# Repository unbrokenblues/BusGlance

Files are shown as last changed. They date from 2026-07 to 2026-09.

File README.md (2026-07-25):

# BusGlance

A tiny ESP32 + 4.2" e-paper display that shows live Singapore bus arrival
times (from LTA DataMall) for two stops, plus a daily uplifting quote.
Battery-powered, sleeps overnight, and pings your phone when the battery is low.



## Features

- **Live bus times** for a home stop and the opposite stop, refreshed every 60s.
- **Fast black & white e-paper** (~1.2s refresh) with a Bauhaus-minimalist layout.
- **"Arriving soon" tag** — buses <= 3 min show white-on-black.
- **365 built-in quotes** (scripture, motivation, manifesting), one per day.
- **Battery smart:** sleeps 00:00-05:00 with WiFi off; on-screen low-battery
  icon plus a phone push via [ntfy.sh](https://ntfy.sh).
- Runs ~10 days on a 2000 mAh LiPo.

## Hardware

- ESP32 dev board (classic ESP32)
- WeAct 4.2" e-paper, 400x300 (driven in black & white)
- LiPo battery (2000 mAh)

Wiring and full build notes are in [PROGRESS.md](PROGRESS.md).

## Setup

1. Install [arduino-cli](https://arduino.github.io/arduino-cli/) and the ESP32 core:
   ```bash
   arduino-cli core install esp32:esp32
   arduino-cli lib install GxEPD2 ArduinoJson
   ```
2. Copy the secrets template and fill in your own values:
   ```bash
   cp bus_display/secrets.h.example bus_display/secrets.h
   ```
   Set your WiFi, your [LTA DataMall](https://datamall.lta.gov.sg/) API key,
   and a private ntfy topic.
3. Adjust the stops, bus numbers, and options at the top of
   `bus_display/bus_display.ino`.
4. Build and upload:
   ```bash
   cd bus_display
   arduino-cli compile --fqbn esp32:esp32:esp32 .
   arduino-cli upload -p YOUR_PORT --fqbn esp32:esp32:esp32 .
   ```

## Note

`secrets.h` is git-ignored so your WiFi password and API key never get
committed. Never commit real credentials.

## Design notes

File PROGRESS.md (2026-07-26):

# BusGlance — Progress Notes

_Last updated: 2026-07-27_

## Update 2026-07-27 — live on hardware

- **Flashing DONE.** Firmware runs on the real board: WiFi + LTA + weather all
  live, crisp black-on-white, overnight sleep re-enabled (`DEBUG_NO_NIGHT_SLEEP
  = false`).
- **Partial refresh does NOT work on this panel.** Tested on hardware: partial
  updates render as grey, ghosted mush (this is a 3-color GDEY042Z98 panel
  driven as B/W). Kept the light-sleep + partial-refresh plumbing but set
  `FULL_REFRESH_EVERY = 1` (full refresh every cycle = crisp, with the black
  flash). The flash takes ~10-14s to settle — unavoidable on this panel.
- **Fix = swap to a TRUE B/W panel: `GDEY042T81`** (WeAct 4.2" Black-White,
  SSD1683, ~$19.46, WeAct Studio Official Store on AliExpress). Confirmed by a
  buyer review running it with partial refresh. Drop-in: same wiring, same case,
  same driver — just set `FULL_REFRESH_EVERY = 15` for smooth flash-free ~0.4s
  partial refresh. NOT yet ordered.
- **Font/icon polish:** minutes auto-shrink so 3-digit bus numbers never overlap
  the "N min"; weather icons redrawn as uniform 2px outlines.
- **Battery:** LiPo confirmed safe (board `+` = red wire). Charge via USB-C
  (board charges while running). Battery low-warning (on-screen + ntfy push to
  topic `busglance-dicky`) is a no-op on this board — pin 35 can't read VBAT, so
  it fail-safes silent. Decision: just **charge weekly** (~7-10 day runtime).

An ESP32 + 4.2" e-paper display that shows live Singapore bus arrival times
(LTA DataMall) for two stops, plus a daily uplifting quote. Battery-powered,
sleeps overnight.

---

## Status at a glance

- **Software: DONE.** The sketch compiles cleanly (arduino-cli, ESP32 core).
- **Blocked on ONE hardware step:** the ESP32's header pins need to be
  **soldered on** before anything can connect. A soldering iron kit (KIPRUN,
  ~$13) was ordered. Everything else is solderless.
- **Not yet uploaded** to the board (waiting on the soldering).

**When you come back:** get the pins soldered → wire the display (map below)
→ plug in USB-C → upload → verify. Roughly 15 minutes once the iron is here.

---

## Hardware inventory

| Item | What it is | Notes |
|---|---|---|
| ESP32 "Lite" (USB-C) | The brain. Confirmed **classic ESP32** (so GPIO 23/18 = SPI). | Came with **loose header pins** — must be soldered on. |
| WeAct 4.2" e-paper, 400x300 | The screen. Physically a **3-color (b/w/red)** panel (GDEY042Z98). | Driven in **black & white** on purpose (see decisions). Factory demo showed red = confirmed 3-color. |
| Rainbow JST cable | 8-wire cable, JST plug → 8 female DuPont ends. | Plugs into the display's white socket (no solder). Other end pushes onto ESP32 pins. |
| 2x4 pin block (spare) | Alt connector for the display. | **Not used** — we use the JST cable. |
| 2 long pin strips | Male headers for the ESP32 edges. | These get soldered onto the ESP32. |

---

## Wiring map (display label → ESP32 pin)

Plug the JST cable into the display's white socket, then push each wire onto
the matching ESP32 pin. **Power is 3.3V — never 5V.**

| Display pin | ESP32 pin | Purpose |
|---|---|---|
| VCC | **3V3** | power (3.3V only) |
| GND | **GND** | ground |
| SDA | **GPIO23** | data (labeled SDA but it's SPI MOSI) |
| SCL | **GPIO18** | clock (labeled SCL but it's SPI SCK) |
| CS  | **GPIO5**  | chip select |
| D/C | **GPIO17** | data/command |
| RES | **GPIO16** | reset |
| BUSY| **GPIO4**  | busy |

Leave the display's "3-Lines / 4-Lines SPI" jumper at its factory setting.

**You do NOT need to solder all the ESP32 pins.** Only these matter:
`3V3, GND, 23, 18, 5, 17, 16, 4` (+ `35` if using the battery monitor).
On this board, the left edge (USB-C at top) conveniently has 3V3 + all six
display signals (23,18,5,17,16,4) — solder that whole strip. GND and 35 are on
the other edge — solder at least GND (and 35), plus a support pin so the strip
isn't wobbly. Skip the rest. Battery: 2000 mAh LiPo (~10 days/charge).

---

## Key settings (top of `bus_display/bus_display.ino`)

- **WiFi + LTA API key:** set in `bus_display/secrets.h` (git-ignored). Copy
  `secrets.h.example` to `secrets.h` and fill in your values.
- **Stops:** Home = `59399` (buses 807, 860, 806, 663) · Opposite = `59391` (buses 804, 807).
- **Refresh:** every `REFRESH_SECONDS = 60`.
- **Active hours:** 05:00–24:00. Sleeps 00:00–05:00 with WiFi off.
- **Battery monitor:** on-screen low-batt icon + phone push (ntfy.sh). Reads
  `BATTERY_ADC_PIN = 35` (÷2 divider), warns below `LOW_BATT_VOLTS = 3.45`.
  Set `NTFY_TOPIC` to something private; fail-safe if the pin isn't wired.
- **Charge frequency:** ~once a week on a 1500–2000 mAh LiPo (draw ~200 mAh/day,
  dominated by the 60s WiFi wakes). Cheap-board idle draw is the wild card.

---

## Design decisions (why things are the way they are)

1. **Black & white, not red.** The panel is physically 3-color, but 3-color
   mode is stuck at ~15s refresh + a 3-minute minimum interval. Driving it in
   B/W (the `GDEY042T81` driver) unlocks a **~1.2s fast refresh with no
   minimum**, so we can update every 60s. Verified against the datasheet and
   the installed library. Red was the *only* thing forcing slow updates.
2. **"Arriving soon" cue = black tag.** A bus <= 3 min away (or NOW) shows its
   minutes as **white text on a filled black box** (replaces the red idea,
   works in B/W, and is more Bauhaus anyway).
3. **Layout = Bauhaus minimalist.** Centered uppercase HOME / OPPOSITE on solid
   black bars; Home in a 2x2 grid; Opposite side-by-side; numbers hard-left,
   minutes hard-right on a clean grid.
4. **Overnight sleep saves battery.** Old code hit WiFi every wake all night.
   Now it reads the clock from the ESP32's RTC (kept alive through deep sleep)
   and, if it's 00:00–05:00, sleeps straight to 5am **without powering WiFi**.
5. **Quotes are built-in, not an API.** Researched quote APIs live: Quotable is
   dead, DummyJSON has mangled capitalization, FavQs can be dark, Bible verses
   are mostly too long. Most stable = a **built-in curated list**. Now **365
   quotes** (scripture + affirmations + proverbs + classic motivation), one per
   day by date, all validated ASCII + short. Zero network, nothing to maintain.

---

## VERIFY ON FIRST BOOT (the 3 things we couldn't test without hardware)

1. **Display driver line.** We drive a 3-color panel in B/W mode. Very likely
   fine (same SSD1683 controller), but if the screen is **blank, faint, or
   ghosted**, that's the switch to flip. Search `DISPLAY DRIVER` in the sketch.
2. **HTTPS / TLS.** Both the bus fetch and (previously) quotes use HTTPS. If
   fetches fail on the real board, the fix is a `WiFiClientSecure` +
   `client.setInsecure()` before `http.begin(...)`. Quick change.
3. **RTC time across deep sleep.** The overnight-sleep logic assumes the clock
   survives deep sleep (standard ESP32 behavior). Confirm it wakes correctly
   at ~5am and doesn't sit online all night.
4. **Battery-voltage pin.** The Serial log prints `Battery volts:` each cycle.
   Confirm it reads realistically (~3.7–4.2V on a charged LiPo). If it prints
   -1 or nonsense, the board doesn't expose battery voltage on pin 35 — either
   fix `BATTERY_ADC_PIN`/`BATTERY_DIVIDER`, add a 2-resistor divider, or set
   `BATTERY_MONITOR = false`. Also set up ntfy (below) for the phone push.

---

## Exact next steps

1. **Solder the two header strips onto the ESP32** (pins pointing down, USB-C
   side up). Or have a makerspace/shop do it.
2. **Wire the display** using the map above (all unplugged from USB).
3. **Plug in USB-C.** Find the serial port:
   ```bash
   arduino-cli board list
   ```
4. **Upload** (replace PORT with what step 3 shows, e.g. /dev/cu.usbserial-XXXX):
   ```bash
   cd "/Users/dickyagustiady/Projects/BusSchedule/bus_display"
   arduino-cli upload -p PORT --fqbn esp32:esp32:esp32 .
   ```
   (If upload fails to start, hold the BOOT button on the ESP32 while it connects.)
5. **Watch the serial log** to confirm WiFi + fetch:
   ```bash
   arduino-cli monitor -p PORT -c baudrate=115200
   ```

To recompile after any edit:
```bash
cd "/Users/dickyagustiady/Projects/BusSchedule/bus_display"
arduino-cli compile --fqbn esp32:esp32:esp32 .
```

---

## First-time soldering cheat sheet (for the header pins)

The easiest kind of soldering — big holes, forgiving. Steps:

1. Let the iron reach ~350C (the kit's digital display shows temp).
2. Sit the pin strip in the ESP32's holes, **plastic spacer flush**, USB side up.
3. **Solder ONE end pin first**, then check the strip sits straight/flush. If
   it tilted, re-melt that joint and nudge it square. *Then* do the rest.
4. Per joint: touch the iron to the pin **and** the gold ring for ~1 second,
   feed a little solder into the joint (not onto the tip), remove solder, then
   remove iron. You want a small shiny cone, not a blob.
5. GND pins take a touch longer to heat (they sink heat) — be patient.
6. Do all pins on both strips so the header is mechanically solid.
7. Rest the hot iron in its stand; wet the sponge to wipe the tip.

Then the display side is 100% solderless — the JST cable just clicks in.

---

## Environment (already set up on this Mac)

- `arduino-cli` v1.5.1 (via Homebrew)
- ESP32 core `esp32:esp32` v3.3.11
- Libraries: GxEPD2, ArduinoJson (+ Adafruit GFX/BusIO)
- Board FQBN: `esp32:esp32:esp32`
- Sketch: `BusSchedule/bus_display/bus_display.ino` (compiles at ~86% flash)

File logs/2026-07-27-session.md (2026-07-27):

# BusGlance / Waktu Session Log — 2026-07-27

Long session. Took BusGlance from a jumper-wire prototype to a trustworthy,
cordless device, rebuilt the case off the real board model, and made key
product decisions for Waktu.

## Display / firmware (bus_display.ino)
- **3 bus timings per service** (NextBus/2/3): big next + two small raised numbers.
- **Dropped "min"** from the numbers; added a tiny **"MIN" legend** on the right of
  each bar.
- **"NOW" → "0"** (arriving = 0 min) — compact, no overlap.
- **Sticky weather**: keep last-good reading on a failed fetch instead of blanking.
- **Weather icon raised + rain drops shortened** so they clear the temp text.
- **Fail-loud failsafe** (the big safety win):
  - Retry NTP **every cycle** (was one-shot at boot) → clock self-heals.
  - Guard `minutesUntilArrival`: no valid clock → return -1 (kills the ~29M
    garbage minutes) + drop absurd (>240min) values.
  - **OFFLINE staleness banner**: if the LTA API isn't reached (or clock invalid)
    for >5 min, a black `! OFFLINE - times as of HH:MM` bar covers the top so
    stale times can never be mistaken for live.

## Case — rebuilt in CadQuery off the REAL board model
- Installed **CadQuery** (system python3 `/usr/bin/python3`, v2.5.2).
- Downloaded WeAct's **`WeAct-EpaperModule-4.2 Board 3D.step`** from
  github.com/WeActStudio/WeActStudio.EpaperModule → `case/models/weact_42.step`.
- Extracted EXACT geometry: board **91.8 × 89.8 mm**, holes **3.2mm dia, 2.8mm
  inset** (86.2 × 84.2 hole-to-hole). Confirmed my measured 91×89 was ~right (not
  swapped). Applied exact values to both the trimesh case (`busglance_case.py`)
  and the new CadQuery build (`busglance_case_cq.py`).
- CadQuery case: flat front/back + filleted vertical edges, rounded window
  (shifted so the bottom PCB strip is hidden), display screwed to the front,
  ESP32 **screwed to the back** via its 2 measured M2 holes on a raised-floor
  cradle, USB-C slot moved to the correct back-of-case depth, snap-fit back.
- Fit check: overlaid the real board's holes vs the case pilots → **0.00mm**
  misalignment.
- The messy trimesh `rbox` pillow shape was replaced with real fillets.

## Hardware saga (all resolved)
- **Bent the ESP32 header pins flat** to slim the wire stack (two-pliers method).
- After rewiring, display froze / showed garbage → chased it down: NOT wiring or
  WiFi. Root cause = **NTP timeout on a cold boot** → no clock → 29M garbage
  minutes. Fixed by the failsafe above. (Also learned: `arduino-cli monitor`
  can't read serial through this CH340 dongle — the display is the ground truth,
  not the serial log.)
- **Battery: RESOLVED — it works.** It was just never fully charged. The board
  DOES auto-charge over USB-C; charge LED on = charging, off = full. Runs
  cordless ~7-10 days. Charge weekly.
- **Battery monitor: conclusively impossible on this board.** Ran an ADC scan
  (results shown on e-paper, since serial is dead) across GPIO 32/33/34/35/36/39
  — NO pin carries the battery voltage (all ~142mV floor; none near ~2000mV, none
  shift with USB). So the low-batt icon + ntfy push can't work without adding a
  2-resistor divider to GPIO 34. Decision: charge weekly, skip the monitor.
  Scanner kept at `adc_scan/adc_scan.ino`.

## Product / process decisions
- **Wall mount:** the printed keyholes were non-functional (no head clearance in
  a thin, packed case). Real answer for a light case = **velcro / Command
  strips** (removable, no wall damage). A slide-on bracket is the "proper" option
  if wanted later.
- **Closure:** no super glue (it's permanent AND cyanoacrylate fogs e-paper).
  Use screws / magnets / hot glue / tape.
- **"How do real products look clean inside?"** — custom PCB (bare ESP32 + RTC +
  FPC display connector, no dev board / jumper wires) + injection-molded case.
  The prototype's mess doesn't carry over; its job is to prove firmware + demand.
- **Red on e-paper:** would make refresh ~2× slower (~20s) AND force a ~3-min
  minimum interval → bad for a 60s bus display. Skip red; go true B/W for speed.

## Waktu (PRD updated — Drive-synced, not git)
- **Dropped ALL physical input** — no button, no touch, no rotary dial.
- **Setup via phone WiFi captive portal** (no app; fallback 192.168.4.1);
  **re-entry via power-cycle** ("the plug is the button"). Bluetooth rejected
  (needs an app). Cleaner case (no holes), cheaper BOM.
- RTC locked as **DS3231 (TCXO)** — DS1302/DS1307 drift ~1-2 min/month,
  unacceptable for prayer times; DS3231 ~±1 min/year.
- Prototype BOM ~$28-30; volume ~Rp200-290k vs Rp399-599k retail.

## Current state
- BusGlance: working, cordless, fail-loud. Firmware + CadQuery case committed.
- Still to order: true B/W **GDEY042T81** panel (drop-in, fast refresh; buy 2 —
  one for BusGlance upgrade, one for Waktu). Print the CadQuery case.
- Case depth is 28mm for the (now-slimmer) wire stack — could drop to ~12mm if
  wires are soldered direct / pins trimmed; re-measure the flat stack when ready.

## Pick up next
1. Order 2× GDEY042T81 B/W panels.
2. Print the CadQuery front + back; verify fit with the real board dims.
3. (Optional) slim wiring → shallow case; (optional) GPIO34 divider for batt push.
4. Waktu: start firmware (offline prayer-time calc is the real new work).

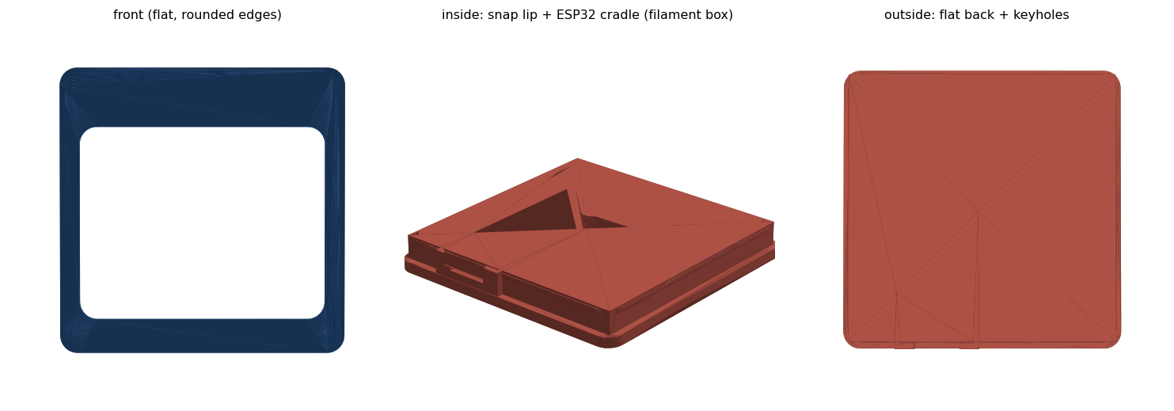
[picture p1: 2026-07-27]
case/preview.png

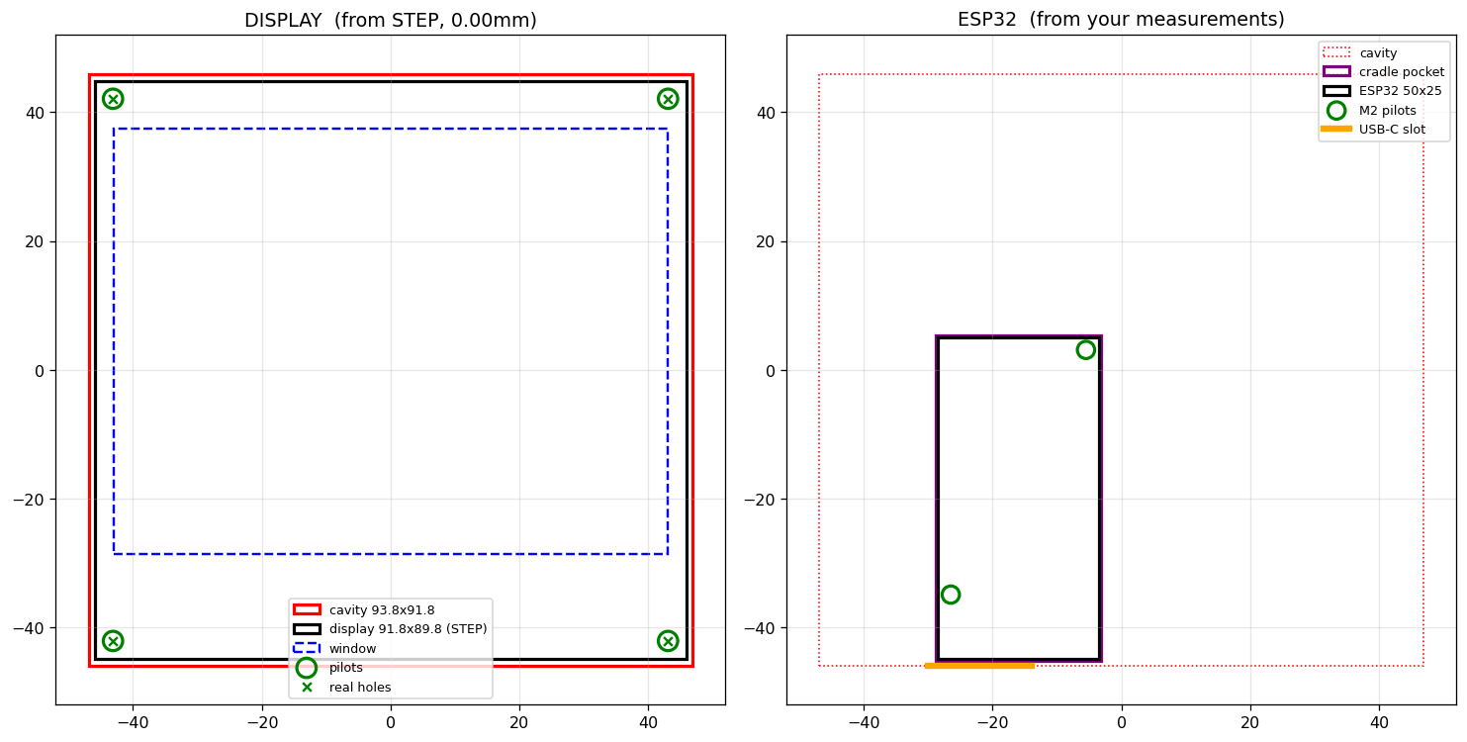
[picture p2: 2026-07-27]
case/fit_check.png

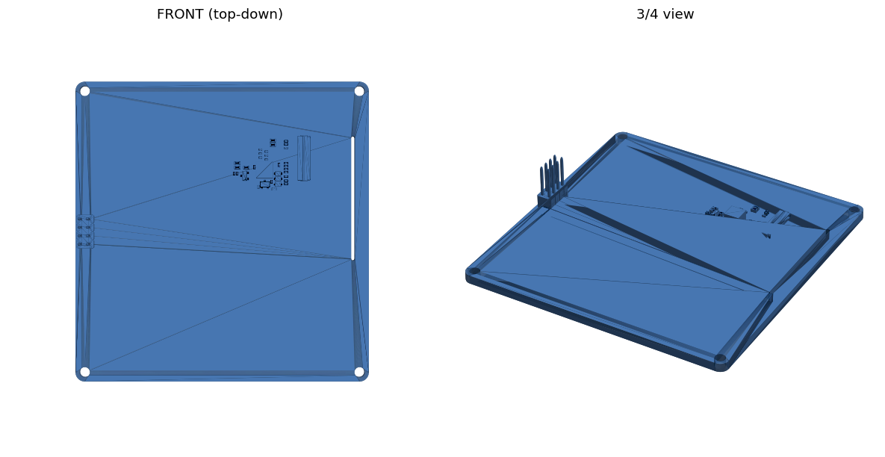
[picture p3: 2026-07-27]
case/models/weact_render.png

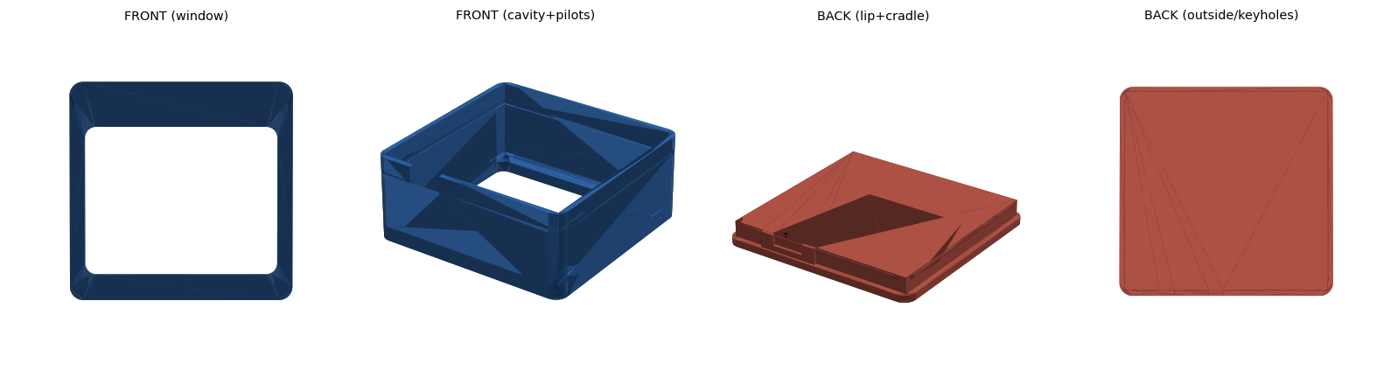
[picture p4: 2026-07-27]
case/preview_cq.png

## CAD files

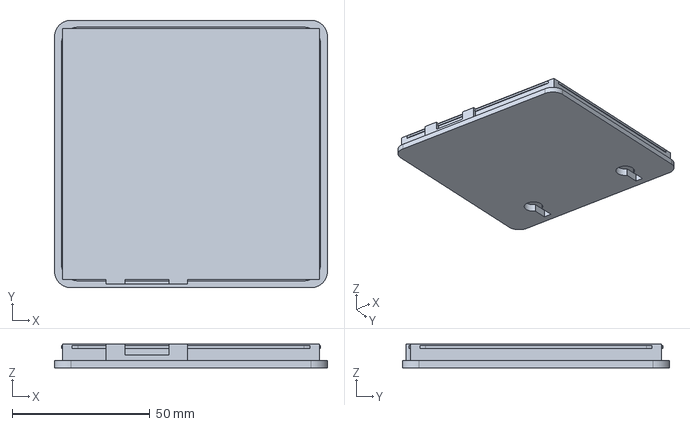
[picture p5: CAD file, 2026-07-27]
case/back_cover.step
99.0 x 97.0 x 8.60 mm

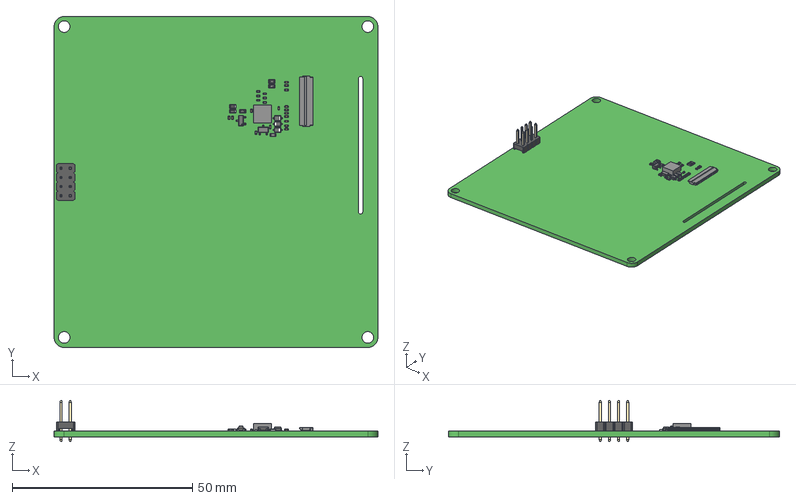
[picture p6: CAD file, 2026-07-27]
case/models/weact_42.step
89.8 x 91.8 x 11.5 mm
R0603 x 5
Extruded x 6
pin_header_awl254-dg-g08d
User Library-SOT23-3
Mid_Body x 9
Mark x 9
Leader x 3
FH34SRJ-24S-0.5SH_RGB4408131
SOD323 x 3

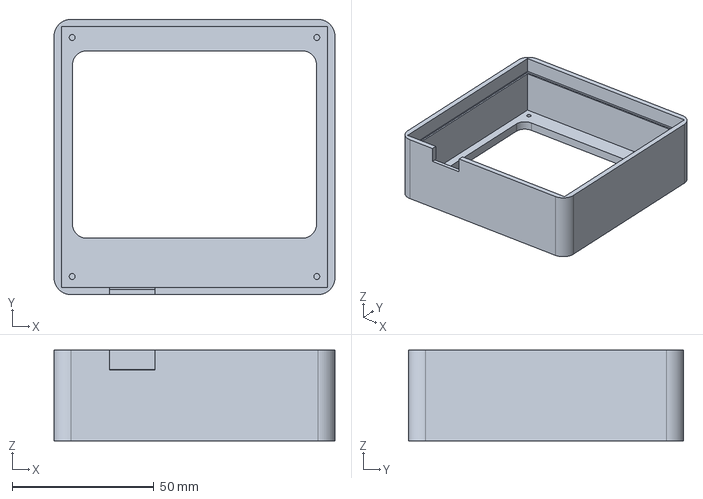
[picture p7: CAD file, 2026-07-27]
case/front_shell.step
99.0 x 97.0 x 32.0 mm

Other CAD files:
case/back_cover.stl
case/front_shell.stl

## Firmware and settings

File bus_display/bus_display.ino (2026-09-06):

/*
  BusGlance - Home Bus Arrival Display
  ESP32 Lite V1.0.0 + WeAct 4.2" E-Paper (400x300)

  WHAT THIS DOES:
  - Connects to WiFi
  - Every 60 seconds (5am - midnight only), fetches live bus arrival
    times from LTA DataMall for two bus stops
  - Draws them on the e-paper screen in black & white, using the panel's
    fast ~1.2s refresh (your stop on top, opposite stop below)
  - Outside 5am-midnight, it sleeps with WiFi off to save battery

  ============ BEFORE YOU UPLOAD ============
  1. Fill in your WiFi name/password below
  2. Your LTA API key is already filled in
  3. Fill in which bus SERVICE NUMBERS you actually want shown
     (e.g. "13", "52", "88") - up to 3 per stop
  4. Check the display driver line (search "DISPLAY DRIVER" below) -
     if the screen shows garbage/nothing, this is the first thing to
     change - tell me and I'll give you the right line.
  ============================================
*/

#include <WiFi.h>
#include <HTTPClient.h>
#include <ArduinoJson.h>
#include <time.h>
#include <esp_sntp.h>
#include <esp_system.h>

#include <GxEPD2_BW.h>
#include <Fonts/FreeSansBold18pt7b.h>
#include <Fonts/FreeSansBold24pt7b.h>
#include <Fonts/FreeSansBold12pt7b.h>
#include <Fonts/FreeSansBold9pt7b.h>
#include <Fonts/FreeSans18pt7b.h>
#include <Fonts/FreeSans9pt7b.h>

// Private credentials live in secrets.h (git-ignored). Copy
// secrets.h.example to secrets.h and fill in your own values.
#include "secrets.h"

// ---------------- USER SETTINGS ----------------

const char* WIFI_SSID     = SECRET_WIFI_SSID;
const char* WIFI_PASSWORD = SECRET_WIFI_PASSWORD;

const char* LTA_API_KEY = SECRET_LTA_API_KEY;

// Your two bus stops
const char* STOP_CODE_HOME     = "59399"; // your stop
const char* STOP_CODE_OPPOSITE = "59391"; // opposite stop

const char* STOP_LABEL_HOME     = "Home";
const char* STOP_LABEL_OPPOSITE = "Opposite";

// Which bus services to show, and in what order.
const char* SERVICES_HOME[4]     = {"807", "860", "806", "663"};
const int   NUM_SERVICES_HOME    = 4;

const char* SERVICES_OPPOSITE[2] = {"804", "807"};
const int   NUM_SERVICES_OPPOSITE = 2;

// Weather (Open-Meteo, free, no API key). Set to your area's coordinates.
const float LATITUDE  = 1.4299;    // your area (northern Singapore)
const float LONGITUDE = 103.8463;
const int   FORECAST_AHEAD_HOURS = 3;  // the "later" slot = now + this many hours

// Refresh interval while awake (seconds). Black & white fast refresh is
// ~1.2s with no 3-minute limit, so we can update often. 60s is a good
// balance of freshness vs battery (30s = fresher but ~half the runtime).
const int REFRESH_SECONDS = 60;

// How often to do a clean FULL (flashing) refresh vs a quiet PARTIAL one.
//   1  => full refresh EVERY cycle: crisp image, but a black flash each time.
//   15 => partial most cycles (no flash) + a full flash ~every 15 min.
// This 3-color panel driven as B/W renders partial refreshes as grey, ghosted
// mush, so we keep it at 1 (full every time). A TRUE B/W GDEY042T81 panel does
// partial cleanly + fast (~0.4s) - swap the panel, then set this to 15.
const int FULL_REFRESH_EVERY = 1;

// A bus this many minutes away (or less) gets the "arriving soon" black tag.
const int SOON_MINUTES = 4;

// DEBUG: while true, the board NEVER sleeps overnight - it keeps refreshing
// 24/7 so we can test past midnight. Set back to false before real use so it
// saves battery by sleeping 00:00-05:00.
const bool DEBUG_NO_NIGHT_SLEEP = false;

// Active hours (24h format) - outside this window the whole board sleeps.
// SG buses run ~5am to midnight, so we sleep 00:00-05:00 to save battery.
const int ACTIVE_START_HOUR = 5;
const int ACTIVE_START_MIN  = 0;
const int ACTIVE_END_HOUR   = 23;
const int ACTIVE_END_MIN    = 59;

// ---- Battery monitor ----
// Only works if your board wires the LiPo to an analog pin (many cheap boards
// do NOT). It's fail-safe: if the reading looks implausible, it stays silent
// instead of false-alarming. On first boot, check the Serial log to confirm
// the voltage is realistic. If your board can't sense it, set this to false.
const bool  BATTERY_MONITOR = true;
const int   BATTERY_ADC_PIN = 34;     // free pin (confirmed via ADC scan) + external 2x100k divider
const float BATTERY_DIVIDER = 2.0;    // external 2x100k divider halves VBAT, so x2 to undo
// Warn below this % (via batteryPercent()'s LiPo curve) - the SAME curve that
// drives the on-screen gauge, so the two can never silently contradict each
// other again. (The old fixed 3.45V threshold actually mapped to ~3% on this
// curve, not the intended ~15-20% - the alert would have fired right before
// shutdown instead of with a useful warning buffer.)
const int LOW_BATT_PERCENT = 15;
const int LOW_BATT_REARM_PERCENT = LOW_BATT_PERCENT + 5;   // re-arm once recovered above this

// Critically low: skip WiFi/HTTPS entirely and just rest. A tired cell can
// brown out mid-WiFi-burst -> reset -> straight back into WiFi -> brownout
// again - a loop with ZERO sleep in between that can drive the LiPo into
// over-discharge. This is the emergency stop for that; no on-screen "charge
// me" UX yet (deliberately deferred), just silently rest and try again later.
const float CRITICAL_BATT_VOLTS = 3.30;
const long  CRITICAL_BATT_SLEEP_SEC = 30L * 60;   // 30 min

// Phone push for low battery via ntfy.sh (free, no account). Install the ntfy
// app, subscribe to YOUR topic below, and alerts arrive on your phone. Change
// this to something private and hard to guess.
const char* NTFY_TOPIC = SECRET_NTFY_TOPIC;

// 365 uplifting quotes - one for each day of the year, picked by date.
// A mix of scripture (public-domain KJV phrasing), affirmations,
// proverbs, and classic motivation. All short + ASCII so they fit.
// Add or edit freely; NUM_QUOTES updates itself.
const char* QUOTES[] = {
  "The Lord is my shepherd; I shall not want. - Psalm 23:1",
  "I can do all things through Christ who strengthens me. - Philippians 4:13",
  "Trust in the Lord with all your heart. - Proverbs 3:5",
  "The Lord is my light and my salvation; whom shall I fear? - Psalm 27:1",
  "Be strong and of a good courage. - Joshua 1:9",
  "Weeping may endure for a night, but joy cometh in the morning. - Psalm 30:5",
  "This is the day which the Lord hath made. - Psalm 118:24",
  "The Lord bless thee, and keep thee. - Numbers 6:24",
  "Let not your heart be troubled. - John 14:1",
  "Cast all your anxiety on him, for he cares for you. - 1 Peter 5:7",
  "Rejoice in the Lord always. - Philippians 4:4",
  "God is our refuge and strength. - Psalm 46:1",
  "Be still, and know that I am God. - Psalm 46:10",
  "Delight thyself also in the Lord. - Psalm 37:4",
  "Commit thy way unto the Lord. - Psalm 37:5",
  "The joy of the Lord is your strength. - Nehemiah 8:10",
  "Let all that you do be done in love. - 1 Corinthians 16:14",
  "Faith is the substance of things hoped for. - Hebrews 11:1",
  "And we know that all things work together for good. - Romans 8:28",
  "In everything give thanks. - 1 Thessalonians 5:18",
  "Pray without ceasing. - 1 Thessalonians 5:17",
  "Love is patient, love is kind. - 1 Corinthians 13:4",
  "Love never fails. - 1 Corinthians 13:8",
  "The Lord is good to all. - Psalm 145:9",
  "Wait on the Lord: be of good courage. - Psalm 27:14",
  "They that wait upon the Lord shall renew their strength. - Isaiah 40:31",
  "Fear not, for I am with thee. - Isaiah 41:10",
  "I have loved thee with an everlasting love. - Jeremiah 31:3",
  "For I know the thoughts that I think toward you. - Jeremiah 29:11",
  "Ask, and it shall be given you. - Matthew 7:7",
  "Come unto me, all ye that labour. - Matthew 11:28",
  "Let your light so shine before men. - Matthew 5:16",
  "Blessed are the pure in heart. - Matthew 5:8",
  "Blessed are the peacemakers. - Matthew 5:9",
  "Blessed are the merciful. - Matthew 5:7",
  "With God all things are possible. - Matthew 19:26",
  "Give, and it shall be given unto you. - Luke 6:38",
  "Peace I leave with you, my peace I give unto you. - John 14:27",
  "I am the light of the world. - John 8:12",
  "Ye shall know the truth, and the truth shall make you free. - John 8:32",
  "If God be for us, who can be against us? - Romans 8:31",
  "Be not overcome of evil, but overcome evil with good. - Romans 12:21",
  "Rejoice with them that do rejoice. - Romans 12:15",
  "The fruit of the Spirit is love, joy, peace. - Galatians 5:22",
  "Let us not be weary in well doing. - Galatians 6:9",
  "Be ye kind one to another. - Ephesians 4:32",
  "My God shall supply all your need. - Philippians 4:19",
  "Let the peace of God rule in your hearts. - Colossians 3:15",
  "Whatsoever ye do, do it heartily, as to the Lord. - Colossians 3:23",
  "God hath not given us the spirit of fear. - 2 Timothy 1:7",
  "Let us hold fast the profession of our faith. - Hebrews 10:23",
  "Jesus Christ the same yesterday, and to day, and for ever. - Hebrews 13:8",
  "Draw nigh to God, and he will draw nigh to you. - James 4:8",
  "Every good gift and every perfect gift is from above. - James 1:17",
  "We love him, because he first loved us. - 1 John 4:19",
  "Perfect love casteth out fear. - 1 John 4:18",
  "Thy word is a lamp unto my feet. - Psalm 119:105",
  "The Lord shall preserve thy going out and thy coming in. - Psalm 121:8",
  "I will lift up mine eyes unto the hills. - Psalm 121:1",
  "My help cometh from the Lord. - Psalm 121:2",
  "Bless the Lord, O my soul. - Psalm 103:1",
  "The Lord is merciful and gracious. - Psalm 103:8",
  "O give thanks unto the Lord; for he is good. - Psalm 107:1",
  "The Lord is nigh unto all them that call upon him. - Psalm 145:18",
  "He healeth the broken in heart. - Psalm 147:3",
  "A soft answer turneth away wrath. - Proverbs 15:1",
  "A merry heart doeth good like a medicine. - Proverbs 17:22",
  "In all thy ways acknowledge him. - Proverbs 3:6",
  "Trust in the Lord, and do good. - Psalm 37:3",
  "The name of the Lord is a strong tower. - Proverbs 18:10",
  "Iron sharpeneth iron. - Proverbs 27:17",
  "Train up a child in the way he should go. - Proverbs 22:6",
  "A good name is rather to be chosen than great riches. - Proverbs 22:1",
  "To every thing there is a season. - Ecclesiastes 3:1",
  "Two are better than one. - Ecclesiastes 4:9",
  "The Lord will fight for you. - Exodus 14:14",
  "Be strong and courageous. Do not be afraid. - Deuteronomy 31:6",
  "The eternal God is thy refuge. - Deuteronomy 33:27",
  "The Lord is my rock, and my fortress. - Psalm 18:2",
  "Thou wilt keep him in perfect peace. - Isaiah 26:3",
  "He giveth power to the faint. - Isaiah 40:29",
  "The Lord is my strength and my song. - Psalm 118:14",
  "Let everything that hath breath praise the Lord. - Psalm 150:6",
  "His compassions fail not; they are new every morning. - Lamentations 3:22",
  "Great is thy faithfulness. - Lamentations 3:23",
  "Seek, and ye shall find. - Matthew 7:7",
  "Blessed are they that mourn: for they shall be comforted. - Matthew 5:4",
  "The Lord is gracious, and full of compassion. - Psalm 111:4",
  "He restoreth my soul. - Psalm 23:3",
  "Thou shalt love thy neighbour as thyself. - Mark 12:31",
  "The Lord is good, a strong hold in the day of trouble. - Nahum 1:7",
  "Weeping endures for a night, but joy comes in the morning.",
  "Where focus goes, energy flows.",
  "What you think, you become.",
  "Act as if it were already yours.",
  "I am becoming who I choose to be.",
  "Small steps every day add up.",
  "Today is a fresh start.",
  "I am enough, just as I am.",
  "My mind is calm and my heart is open.",
  "I choose progress over perfection.",
  "Breathe in calm, breathe out doubt.",
  "I attract what I am ready for.",
  "Good things are on their way.",
  "I trust the timing of my life.",
  "I am stronger than my excuses.",
  "Every day I grow a little braver.",
  "I create my own sunshine.",
  "My potential is limitless.",
  "I am grateful for this moment.",
  "Peace begins with a single breath.",
  "I turn setbacks into comebacks.",
  "I am worthy of good things.",
  "My future is bright and open.",
  "I choose courage over comfort.",
  "Progress, not perfection.",
  "I plant seeds of kindness daily.",
  "I am the author of my story.",
  "Focus on the step in front of you.",
  "I release what I cannot control.",
  "My best is always good enough.",
  "I welcome change with open arms.",
  "Confidence grows each time I try.",
  "I am calm, capable, and ready.",
  "Every sunrise is a new chance.",
  "I speak kindly to myself.",
  "I am exactly where I need to be.",
  "Gratitude turns enough into plenty.",
  "I choose joy in the little things.",
  "My dreams are worth the effort.",
  "I rise by lifting others.",
  "Doubt kills more dreams than failure ever will.",
  "I am open to new possibilities.",
  "Today I choose to be present.",
  "I am proud of how far I have come.",
  "Courage starts with showing up.",
  "I water the seeds I want to grow.",
  "My energy is calm and steady.",
  "I am learning and I am growing.",
  "Every day is a chance to begin again.",
  "I let go and let good things flow.",
  "I am the calm in my own storm.",
  "My thoughts shape my world.",
  "I choose to see the good.",
  "I am patient with my progress.",
  "Kindness is never wasted.",
  "I believe in what I am building.",
  "One kind word can change a day.",
  "I trust myself to figure it out.",
  "Great things take a little time.",
  "I am resilient and I keep going.",
  "My heart is full of hope.",
  "I show up for myself today.",
  "Fear is just excitement without breath.",
  "I am grounded, grateful, and glad.",
  "Every effort counts, even the small ones.",
  "I choose thoughts that lift me up.",
  "My calm is my superpower.",
  "I am open to receive good today.",
  "Slow progress is still progress.",
  "I forgive myself and move forward.",
  "I am building a life I love.",
  "Today I plant hope, not worry.",
  "I am capable of amazing things.",
  "My kindness ripples outward.",
  "I meet challenges with a clear mind.",
  "I am worthy of rest and joy.",
  "Each morning offers a clean page.",
  "I choose faith over fear.",
  "My voice matters and I use it kindly.",
  "I am learning to trust the journey.",
  "Good energy flows to me and through me.",
  "I celebrate small wins today.",
  "I am becoming stronger every day.",
  "My patience is a quiet strength.",
  "I let my light shine gently.",
  "I am open, willing, and ready.",
  "Today I choose peace over pressure.",
  "I keep going, even when it is hard.",
  "My gratitude grows what is good.",
  "I am the calm I have been seeking.",
  "Every step forward is a victory.",
  "I trust that I am enough.",
  "I choose to bloom where I am.",
  "My mindset is my greatest asset.",
  "I am gentle with myself today.",
  "Hope lives in my next small step.",
  "I turn worry into wonder.",
  "I am ready for good things.",
  "My courage is bigger than my fear.",
  "I greet today with an open heart.",
  "I am grateful for another day.",
  "Calm mind, brave heart, steady steps.",
  "I choose growth over comfort.",
  "My dreams deserve my effort.",
  "I am at peace with what is.",
  "Today I move at my own pace.",
  "I am worthy of my own kindness.",
  "Little by little becomes a lot.",
  "I trust myself to begin.",
  "My heart leads with kindness.",
  "I am proud to keep trying.",
  "Fresh start, clear mind, open heart.",
  "I choose to rise, not sink.",
  "Every day I choose to grow.",
  "I am the calm within the noise.",
  "My gratitude opens new doors.",
  "I let good habits carry me.",
  "I am steady, strong, and sure.",
  "Today holds a quiet kind of hope.",
  "I keep my heart soft and my will strong.",
  "I am becoming my best self.",
  "I meet this day with gratitude.",
  "My peace is worth protecting.",
  "I choose kindness, always.",
  "Small brave steps change everything.",
  "I am open to joy today.",
  "My effort today builds my tomorrow.",
  "I trust the quiet work of growth.",
  "I am calm, focused, and free.",
  "Today I choose to begin again.",
  "I carry hope wherever I go.",
  "I bend so that I do not break.",
  "My worth is not up for debate.",
  "Every cloud has a silver lining.",
  "Rome was not built in a day.",
  "Where there is a will, there is a way.",
  "Actions speak louder than words.",
  "The early bird catches the worm.",
  "Fortune favors the bold.",
  "A journey of a thousand miles begins with a single step.",
  "Practice makes perfect.",
  "Slow and steady wins the race.",
  "Better late than never.",
  "Hope for the best, prepare for the worst.",
  "A stitch in time saves nine.",
  "Look before you leap.",
  "Many hands make light work.",
  "Honesty is the best policy.",
  "No pain, no gain.",
  "Patience is a virtue.",
  "What goes around comes around.",
  "Kindness is a language everyone understands.",
  "A smile is the best makeup.",
  "Laughter is the best medicine.",
  "Home is where the heart is.",
  "Every day is a second chance.",
  "Good things come to those who wait.",
  "If at first you don't succeed, try again.",
  "Two heads are better than one.",
  "Birds of a feather flock together.",
  "The grass is greener where you water it.",
  "A friend in need is a friend indeed.",
  "Make hay while the sun shines.",
  "Don't count your chickens before they hatch.",
  "The pen is mightier than the sword.",
  "Necessity is the mother of invention.",
  "When the going gets tough, the tough get going.",
  "Still waters run deep.",
  "You reap what you sow.",
  "A calm sea never made a skilled sailor.",
  "Little strokes fell great oaks.",
  "The best is yet to come.",
  "Every ending is a new beginning.",
  "Do unto others as you would have them do unto you.",
  "Kind words cost nothing.",
  "A good deed is never lost.",
  "Great oaks from little acorns grow.",
  "The darkest hour is just before the dawn.",
  "After a storm comes a calm.",
  "Where there is love, there is life.",
  "A problem shared is a problem halved.",
  "Measure twice, cut once.",
  "Well begun is half done.",
  "First things first.",
  "Easy does it.",
  "Live and let live.",
  "Better safe than sorry.",
  "Time heals all wounds.",
  "Absence makes the heart grow fonder.",
  "Give credit where credit is due.",
  "The apple never falls far from the tree.",
  "Strike while the iron is hot.",
  "Don't put off till tomorrow what you can do today.",
  "A penny saved is a penny earned.",
  "Waste not, want not.",
  "Every dog has its day.",
  "It is never too late to learn.",
  "Knowledge is power.",
  "Curiosity is the spark of learning.",
  "A leopard cannot change its spots.",
  "Don't judge a book by its cover.",
  "Beauty is in the eye of the beholder.",
  "The squeaky wheel gets the grease.",
  "When in Rome, do as the Romans do.",
  "There is no place like home.",
  "A chain is only as strong as its weakest link.",
  "The proof of the pudding is in the eating.",
  "All that glitters is not gold.",
  "An apple a day keeps the doctor away.",
  "Empty vessels make the most noise.",
  "Every man is the architect of his own fortune.",
  "God helps those who help themselves.",
  "Good fences make good neighbors.",
  "Half a loaf is better than none.",
  "He who hesitates is lost.",
  "It takes two to tango.",
  "Learn to walk before you run.",
  "Let sleeping dogs lie.",
  "Life is what you make it.",
  "Little things mean a lot.",
  "Make the most of every day.",
  "No news is good news.",
  "Nothing ventured, nothing gained.",
  "One good turn deserves another.",
  "Opportunity knocks but once.",
  "Every mistake is a lesson in disguise.",
  "Practice what you preach.",
  "Rain today, sunshine tomorrow.",
  "Seeing is believing.",
  "The sun will rise again tomorrow.",
  "There is strength in numbers.",
  "Together we are stronger.",
  "Variety is the spice of life.",
  "A grateful heart is a happy heart.",
  "Kindness always comes back around.",
  "Nothing great was ever achieved without enthusiasm. - Emerson",
  "The only way to have a friend is to be one. - Emerson",
  "Write it on your heart that every day is the best day. - Emerson",
  "Always do what you are afraid to do. - Emerson",
  "Do not go where the path may lead; go where there is no path. - Emerson",
  "Make the most of yourself, for that is all there is of you. - Emerson",
  "For every minute you are angry you lose sixty seconds of peace. - Emerson",
  "The person you are meant to be is the one you decide to be. - Emerson",
  "Go confidently in the direction of your dreams. - Thoreau",
  "Success comes to those too busy to be looking for it. - Thoreau",
  "It does not matter how slowly you go as long as you do not stop. - Confucius",
  "The greatest glory is in rising every time we fall. - Confucius",
  "Wheresoever you go, go with all your heart. - Confucius",
  "Real knowledge is to know the extent of one's ignorance. - Confucius",
  "Life is really simple, but we insist on making it complicated. - Confucius",
  "He who conquers himself is the mightiest warrior. - Confucius",
  "The man who moves a mountain begins by carrying small stones. - Confucius",
  "When I let go of what I am, I become what I might be. - Lao Tzu",
  "Nature does not hurry, yet everything is accomplished. - Lao Tzu",
  "Knowing others is wisdom, knowing yourself is enlightenment. - Lao Tzu",
  "He who knows that enough is enough will always have enough. - Lao Tzu",
  "Great acts are made up of small deeds. - Lao Tzu",
  "Your life is what your thoughts make it. - Marcus Aurelius",
  "Waste no more time arguing what a good man should be. Be one. - Marcus Aurelius",
  "Very little is needed to make a happy life. - Marcus Aurelius",
  "You have power over your mind, not outside events. - Marcus Aurelius",
  "Confine yourself to the present. - Marcus Aurelius",
  "Luck is what happens when preparation meets opportunity. - Seneca",
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
void loop() {
  // Never reached - see sleepUntilNextRefresh().
}

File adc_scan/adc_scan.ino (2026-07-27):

/*
  Battery-sense pin finder for BusGlance.
  Reads every ADC1 pin and shows the voltage ON THE E-PAPER (serial is unreadable
  through this dongle). We're hunting for a pin that sits at ~half the battery
  voltage (~1.9-2.1 V) - that's the board's built-in VBAT divider, if it exists.
  A real VBAT pin will also CHANGE a little when you plug/unplug USB.
  Refreshes every ~20 s. Flash bus_display back when done.
*/
#include <GxEPD2_BW.h>
#include <Fonts/FreeSansBold12pt7b.h>
#include <Fonts/FreeSans9pt7b.h>

GxEPD2_BW<GxEPD2_420_GDEY042T81, GxEPD2_420_GDEY042T81::HEIGHT>
  display(GxEPD2_420_GDEY042T81(/*CS=*/5, /*DC=*/17, /*RST=*/16, /*BUSY=*/4));

const int  pins[]  = {32, 33, 34, 35, 36, 39};
const char* names[] = {"32", "33", "34", "35", "36/VP", "39/VN"};

uint32_t readAvg(int pin) {
  uint32_t sum = 0;
  for (int i = 0; i < 32; i++) sum += analogReadMilliVolts(pin);
  return sum / 32;
}

void draw() {
  display.setFullWindow();
  display.firstPage();
  do {
    display.fillScreen(GxEPD_WHITE);
    display.setTextColor(GxEPD_BLACK);
    display.setFont(&FreeSansBold12pt7b);
    display.setCursor(8, 26);  display.print("BATTERY-SENSE SCAN");
    display.setFont(&FreeSans9pt7b);
    display.setCursor(8, 48);  display.print("Find a pin near ~2000mV (=half battery).");
    display.setCursor(8, 66);  display.print("It should shift when USB is un/plugged.");
    int y = 96;
    for (int i = 0; i < 6; i++) {
      uint32_t mv = readAvg(pins[i]);
      char buf[56];
      snprintf(buf, sizeof(buf), "GPIO %-6s  %4u mV   (x2 = %.2f V)", names[i], mv, mv * 2 / 1000.0);
      display.setFont(&FreeSans9pt7b);
      display.setCursor(8, y);
      display.print(buf);
      y += 30;
    }
  } while (display.nextPage());
}

void setup() {
  analogReadResolution(12);
  display.init();
  display.setRotation(0);
  draw();
}

void loop() {
  delay(20000);
  draw();
}

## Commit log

2026-07-25 Initial commit: BusGlance ESP32 e-paper bus display
    ESP32 + WeAct 4.2in e-paper showing live LTA bus arrivals for two stops,
    with a rotating daily quote, overnight deep-sleep, and low-battery alerts
    (on-screen + ntfy push). Credentials live in a git-ignored secrets.h.
2026-07-25 Add weather + date/time header to BusGlance
    Replace the daily quote with a top header: day/date + time on the left,
    and three weather slots (now, +3h, +6h) from Open-Meteo (no API key) on
    the right - outline icons, temperature, and rain chance. Buses moved
    below and spaced to fill the height. Fast B/W refresh at 60s retained.
    [bus_display.ino]
2026-07-25 Add 3D-printable case (parametric OpenSCAD-style, trimesh)
    Rounded Bauhaus enclosure for BusGlance: front frame + back cover.
    - 87x65 rounded screen window, snug USB-C hole
    - 4 tapered locating pips + M2.5x6 BHCS corner bosses
    - countersunk back screws, 2 wall-mount keyholes
    - busglance_case.py regenerates both STLs; preview.png included
    [back_cover.stl, front_shell.stl]
2026-07-26 Full-refresh-only on this panel; polish fonts/icons; add partial-refresh infra
    - Partial refresh confirmed broken on the 3-color panel (grey/ghosted); kept
    light-sleep + partial plumbing but set FULL_REFRESH_EVERY=1 (crisp full every
    cycle). Swap to true B/W GDEY042T81 + set 15 for flash-free partial.
    - Minutes auto-shrink so 3-digit bus numbers never overlap the tag.
    - Weather icons redrawn as uniform 2px outlines.
    - Re-enabled overnight battery-saving sleep (DEBUG_NO_NIGHT_SLEEP=false).
    - Add partial_test sketch used to characterise the panel.
    - PROGRESS.md: hardware findings, panel-to-order, weekly-charge decision.
    [bus_display.ino, partial_test.ino]
2026-07-27 Case: fit real board (91x89), deepen for wire stack, screw display to front, snap-fit back
    - Rectangular fit 91x89 + 1.25mm/side clearance (was too tight, wouldn't drop in)
    - Flat front + back, only vertical edges rounded (was pillowed)
    - Depth 28mm for the 25mm display+wire connector stack
    - Window sized to active glass, shifted up 9mm to match the offset screen
    - Display screwed to the thick flat front (exact hole grid 86x84, 2.5mm inset, 3mm holes)
    - Removed fragile tall standoffs; back is now a snap-fit lid (ridge+groove)
    - ESP32 held in a bottom-left cradle; USB-C slot bottom-left
    [back_cover.stl, front_shell.stl]
2026-07-27 Display: 3 timings/bus + MIN legend; case: screw down the ESP32
    Firmware (bus_display.ino):
    - Show next 3 buses per service (NextBus/2/3): big next + two small raised
    - Drop 'min' from numbers; add tiny 'MIN' legend on the right of each bar
    - 'NOW' -> '0' (compact, no overlap with the follow-up numbers)
    - Raise the weather icon + shorten rain drops so they clear the temp text
    - Sticky weather: keep last-good reading on a failed fetch instead of blanking
    Case (busglance_case.py):
    - ESP32 now screws to the back plate via its 2 measured M2 holes,
    on a raised-floor cradle (support + thread depth); USB-C slot aligned
    - Fixed stale render labels (no more 'tubes'/'screw c-bores')
    [back_cover.stl, front_shell.stl]
2026-07-27 Case: rebuild in CadQuery, fit to the REAL WeAct 4.2 board model
    - Download WeAct-EpaperModule-4.2 Board 3D.step; extract exact geometry:
    board 91.8x89.8, holes 3.2mm dia @ 2.8mm inset (86.2x84.2 spacing)
    - New CadQuery build (busglance_case_cq.py): clean CSG, filleted edges,
    STEP + STL output. Fixed USB slot depth (now at the ESP32/back, not front)
    - Fit check vs the real STEP: display pilots align to 0.00mm; ESP32 placed
    from measured holes with cradle + USB-C slot verified
    - Also updated the trimesh case with the exact model dimensions
    - ESP32: no exact STEP exists for the generic clone; measured holes are the
    reliable source and are used as-is
    [back_cover.step, back_cover.stl, front_shell.step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]
2026-07-27 Firmware failsafe: fail loud when data is stale, never show garbage
    - Retry NTP every cycle (was one-shot at boot) so a failed clock self-heals
    - Guard minutesUntilArrival: no valid clock -> return -1 (kills the ~29M garbage
    minutes seen when NTP hadn't synced), and drop absurd (>240min) values
    - OFFLINE staleness banner: if the LTA API isn't reached (or clock invalid) for
    >5min, overlay a black '! OFFLINE - times as of HH:MM' bar so old bus times
    can never be mistaken for live data
    [bus_display.ino]
2026-07-27 Add ADC battery-sense scan + 2026-07-27 session log
    - adc_scan/: diagnostic that prints ADC pin voltages to the e-paper (serial is
    unreadable through the CH340 dongle). Confirmed no built-in VBAT sense on this
    board -> low-batt monitor needs an external divider.
    - logs/2026-07-27-session.md: full session record (display polish, CadQuery case
    off the real WeAct STEP, fail-loud failsafe, battery resolved, Waktu no-button).
    [adc_scan.ino]
2026-08-20 Fix clock drift: re-sync NTP every 30min, not just once
    Once NTP synced successfully at boot, the firmware never checked the real
    clock again for the rest of the day. Switching to continuous light-sleep
    (for partial-refresh) gave the ESP32's internal oscillator many hours to
    drift before any correction, which silently undercounted every bus's
    'minutes away' -> some buses that were still 2-3min out got clamped to 0
    and shown as falsely arriving/arrived. Fix: track g_lastSyncEpoch and
    re-sync NTP every NTP_RESYNC_SECONDS (30min) regardless of prior success.
    [bus_display.ino]
2026-08-20 Tighten NTP resync to every 10min (was 30min)
    WiFi is already active every 60s cycle for bus+weather fetches, so an extra
    NTP packet (~50 bytes) is essentially free battery-wise. Tighter resync caps
    clock drift sooner, reducing the window where growing drift could make
    still-arriving buses falsely read as 0/NOW for multiple refreshes in a row.
    [bus_display.ino]
2026-09-06 Fix battery drain regression + add battery-voltage divider support
    Battery life had regressed from ~7-10 days to ~3 days per charge. Root
    causes (found across three independent review passes):
    - Reverted inter-cycle sleep from light sleep back to deep sleep. Light
    sleep was only needed for e-paper partial refresh, which this 3-color
    panel can't do cleanly anyway (renders grey/ghosted) - so it was pure
    waste. Every wake now reboots into setup() fresh; loop() is dead code.
    - display.hibernate() was never being called - the panel stayed
    semi-awake 24/7, including overnight. Now hibernates after every draw.
    - Migrated weather-data globals to RTC_DATA_ATTR so "sticky weather on
    failed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
    [bus_display.ino]
